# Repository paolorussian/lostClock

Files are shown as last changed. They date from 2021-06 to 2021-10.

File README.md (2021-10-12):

# "Swan" station flip-clock project files:
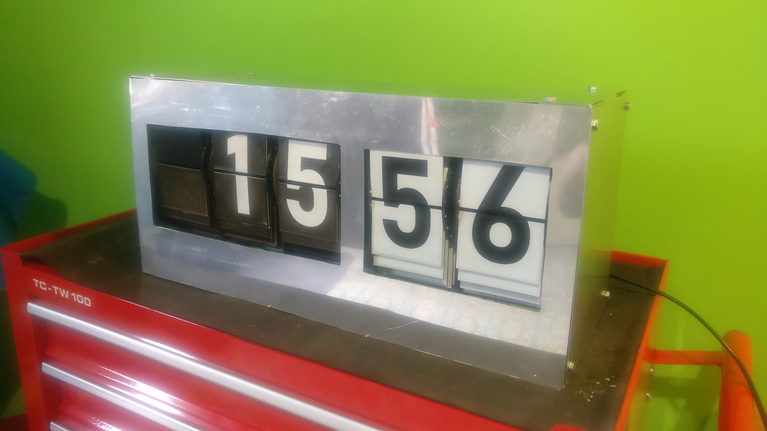
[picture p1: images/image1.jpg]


## THIS IS NOT A TUTORIAL

This LOST clock replica is a raspberry pi - based device which emulates the 108 minute countdown from the show, but can also function as a regular clock. Mode switch can be made by pushing an html button in a web server running from the same single python file.

Please note that, believe it or not, the clock in the show was added in computer graphics, meaning that some of its features cannot be 100% accurate in any replica: not only the case has no visible bolts or screws, but also the flaps should "magically change" from being only digits to only hieroglyphs. In the real world, we need bolts and also accommodate digits and hieroglyphs in the same flap drums, meaning that as the clocks runs through the digit flaps and then is supposed to start over (9,8,7,6,5,4,3,2,1,0.... 9 again) you will see the hieroglyphs briefly passing by, as the hieroglyph flap does exist and must be placed somewhere.

Also note that in this project the numbering is [0,1,2,3,4,5,6,7,8, BLANK, HIEROGLYPH, 9,8,7,6,5,4,3,2,1] totalling 20 flaps each drum. You may have noticed that the digits are duplicated: this is not an error, as in order to function also as a regular clock we should have also ascending numbers. This is because in split-flap displays like this drums can only turn in one direction meaning that if you want to obtain a countdown timer (like the one from the show) you should have descending numbers to minimize the amount of flaps skipped minute after minute. But if you want it to also function as a regular clock then without ascending numbers you would have to use the descending, but each time the drum advances one digit, to get to the next flap it would need to run through all the 19 following flaps every minute (or second). Having both descending and ascending numbering, we can use only the descending for the countdown mode, and only the ascending for the clock mode. 0 is shared intentionally and also the 9 because I'm lazy and I didn't modify my print to accommodate 21 flaps instead of 20.

### required materials and components
- a raspberry pi (Pi3B+, PI4, or Zero W)
- 5 * 28BYJ-48 stepper motors with 
- 5 * motor drivers UNL2003
- 5 * KY-010 photo interrupters
- 5 * ball bearings 5mm * 11mm * 4mm
- 5V 3A stabilized power adapter (to power the thing from regular 220v lines or plugs)
- lots of dupont cables or whatever you prefer to use for connections
- a couple of 3.5mm * 1mm * 1m flat aluminum profiles
- a couple of 6mm diameter * 1m cylinder hollow alumunum profiles 
- a couple of 4mm * 1m screw bar (metal rods that basically are endless screws, like in 3d printer shafts). this and the previous are needed to hold the frame together
- m4 nuts and bolts of various length
- m2 nuts and bolts for the photo interrupter tiny holes
- 1mm headless nails (you need to insert one of these nails in the drum little hole so that it passes through the photo interrupter each drum turn, auto-configuring the motor initial position, which in case you power off the device there is no way to know otherwise)
- black spray paint (not really necessary)

### what do you need to 3D print (stl included in the project's stl directory)
- 5 * drum L
- 5 * drum R
- 100 flaps (20 each drum)

## Assembly

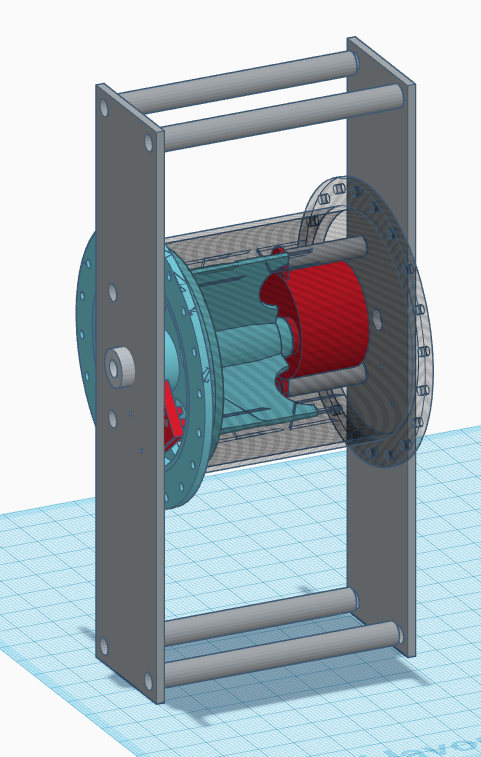
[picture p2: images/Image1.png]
fully assembled
 *an assembled single drum*

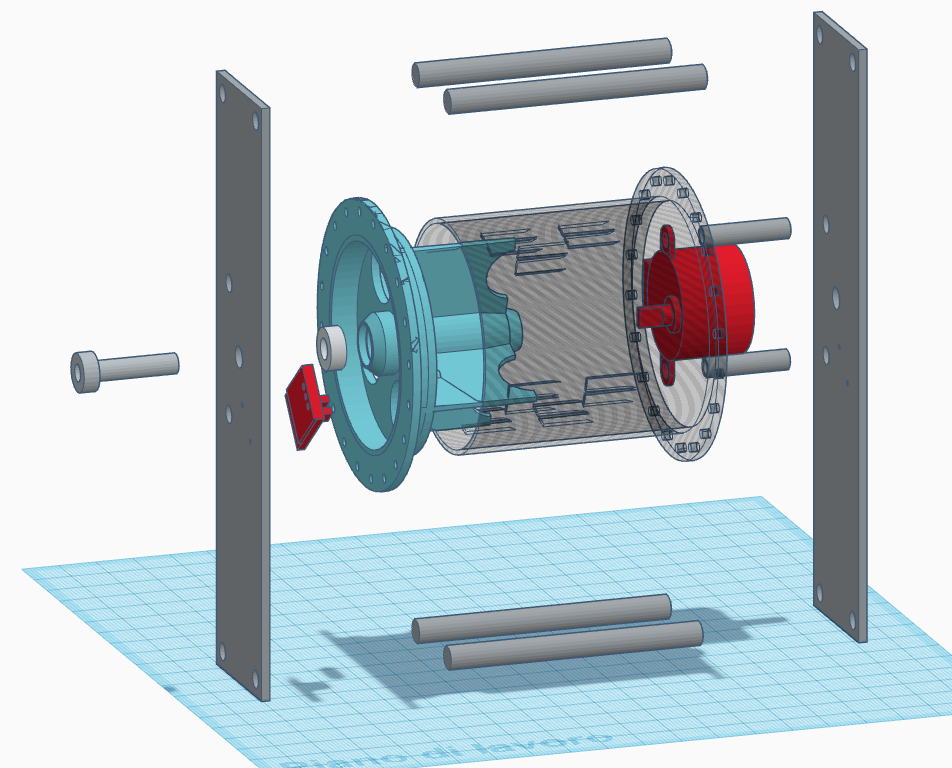
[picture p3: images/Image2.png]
disassembled
 *an exploded single drum*

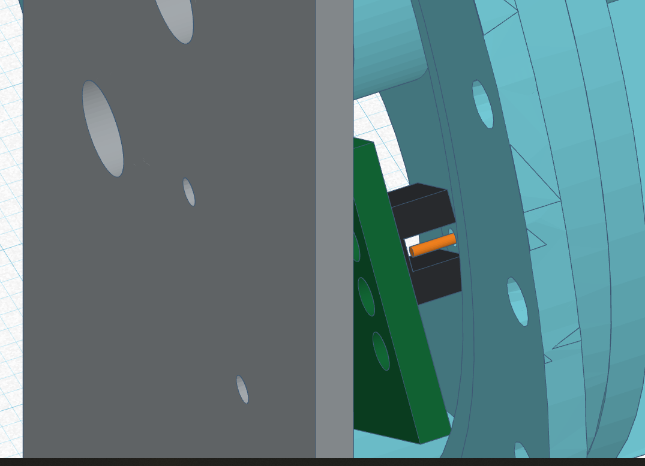
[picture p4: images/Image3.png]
nail and photo interrupter
 *nail and photo interrupter*

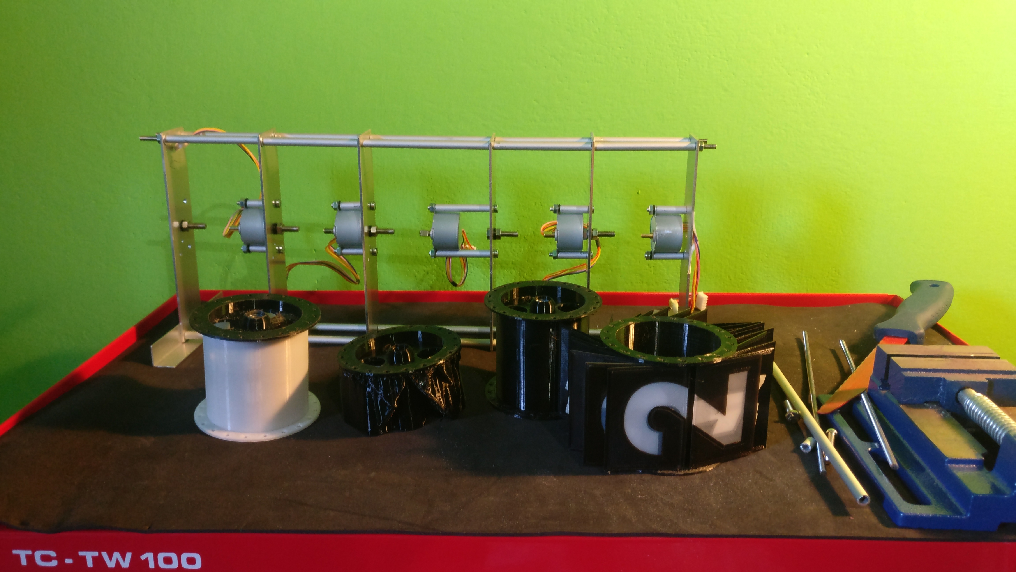
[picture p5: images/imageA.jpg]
frame assembled partial
 *unfinished frame assembled*

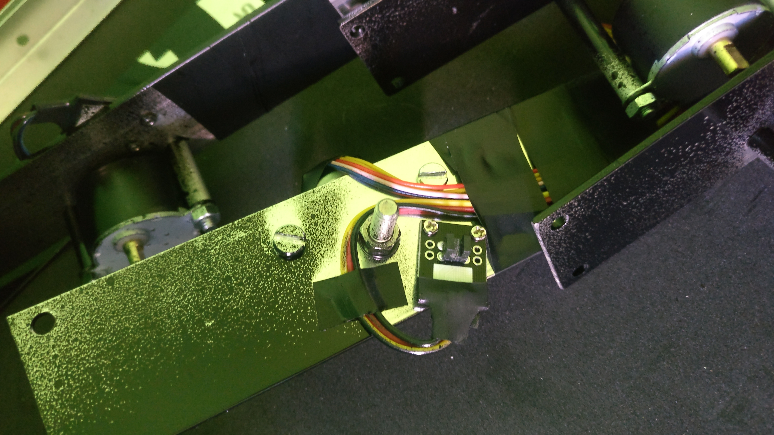
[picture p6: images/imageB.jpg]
photo interrupter
 *photo interrupter*

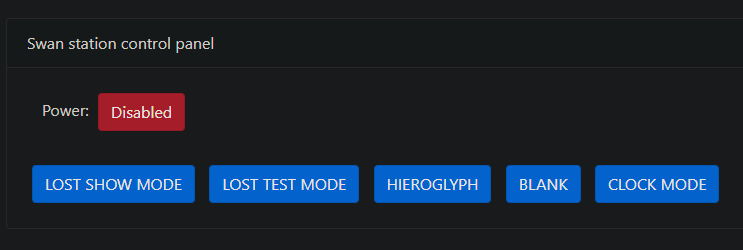
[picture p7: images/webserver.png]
webserver


*web interface to switch between modes*
- lost show mode: full 109 minute timer (108.59.99...), under 4 minutes "seconds" drums are enabled, with sounds (volume 100%)
- lost test mode: same as lost show mode but the timer starts at 2 minutes, with 50% volume
- hieroglyph: displays hieroglyphs on each drum (static)
- blank: display blank flaps on each drum (static)
- clock mode: works as a regular HH:MM clock. As the raspberry pi hasn't got any battery to store time, and there's no real time clock, time is got from the internet as soon as the raspberry pi manages to connect to the wifi. It usually takes a minute or two, depending on the signal strenght and (mostly) Murphy's laws.

credits:
https://www.thingiverse.com/thing:3493999 Martin1111 for the drum and flap design, which, however got modified to accommodate other components.

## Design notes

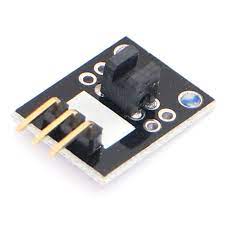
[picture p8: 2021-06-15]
images/ky010.jpg

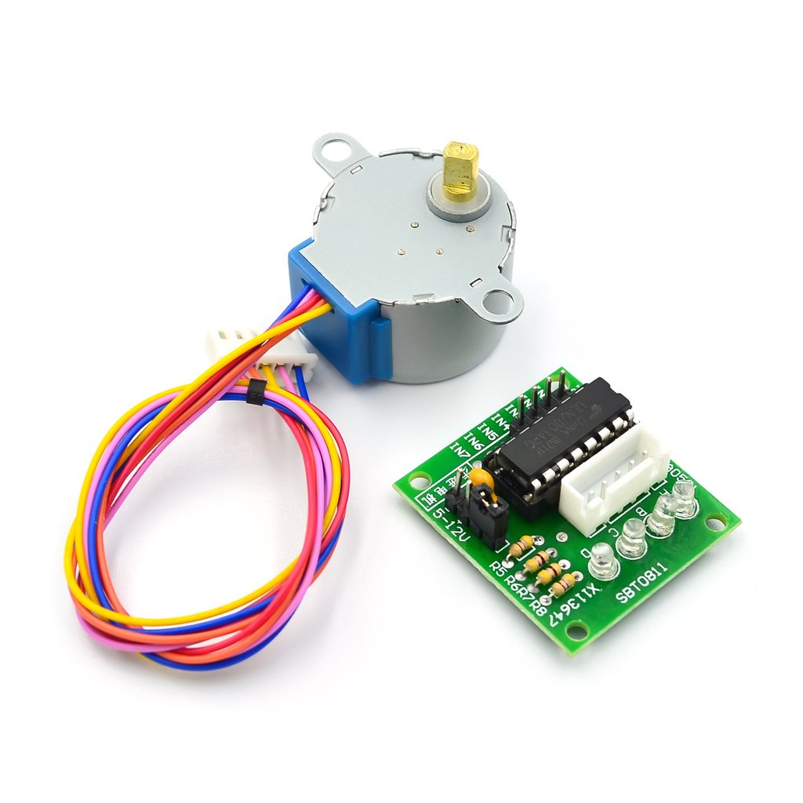
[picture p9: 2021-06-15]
images/motor.jpg

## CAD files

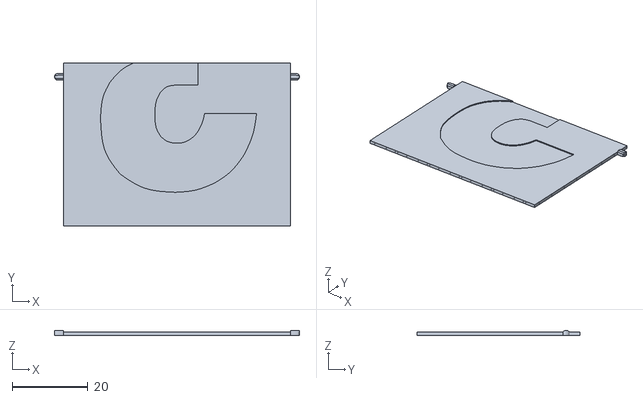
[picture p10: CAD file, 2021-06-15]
stl/C2.stl
64.9 x 43.1 x 1.20

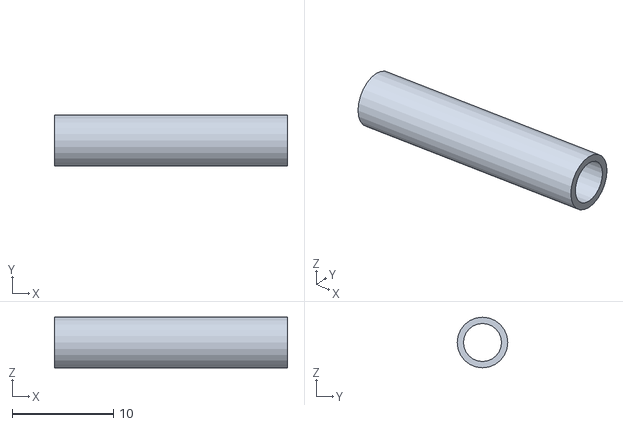
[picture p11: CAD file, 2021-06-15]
stl/supportB.stl
23.0 x 5.00 x 5.00

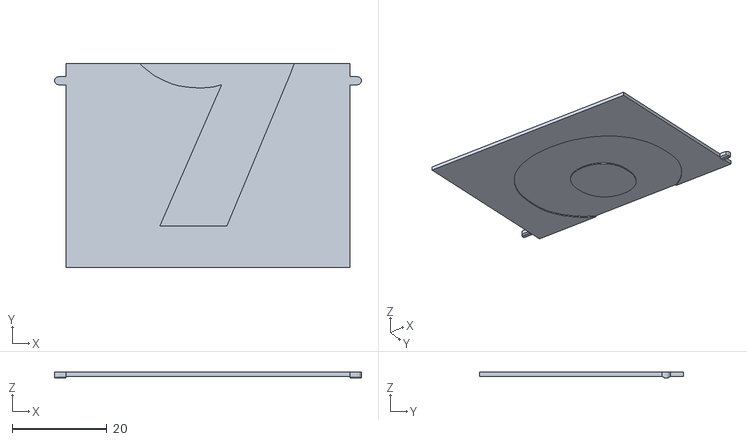
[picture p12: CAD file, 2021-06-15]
stl/F9.stl
64.8 x 43.1 x 1.20

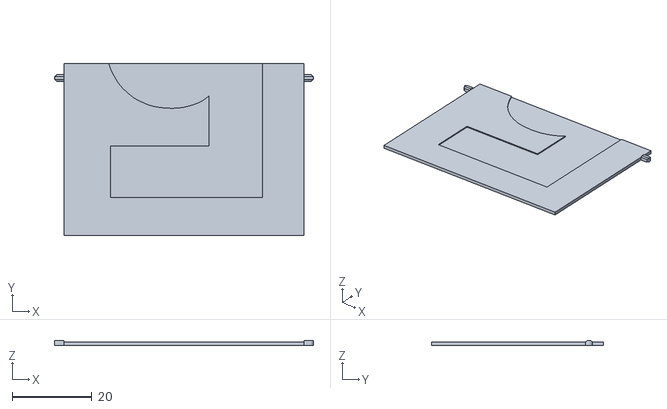
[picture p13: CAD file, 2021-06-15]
stl/C4.stl
64.9 x 43.1 x 1.20

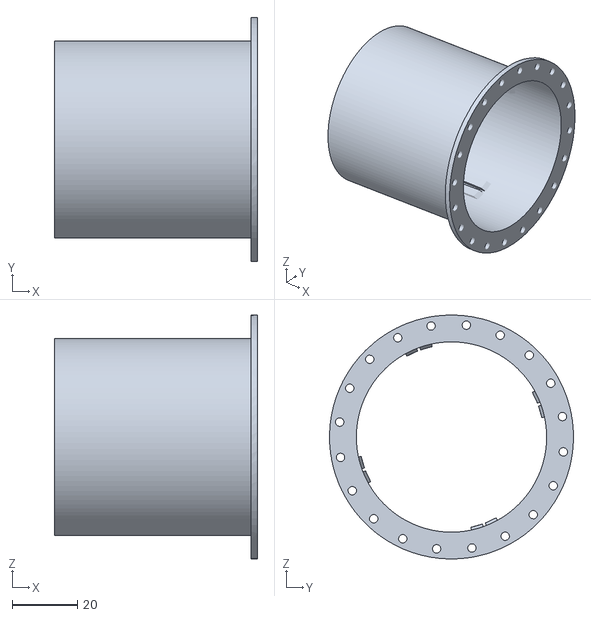
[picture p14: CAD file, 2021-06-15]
stl/drumR.stl
62.5 x 75.0 x 75.0

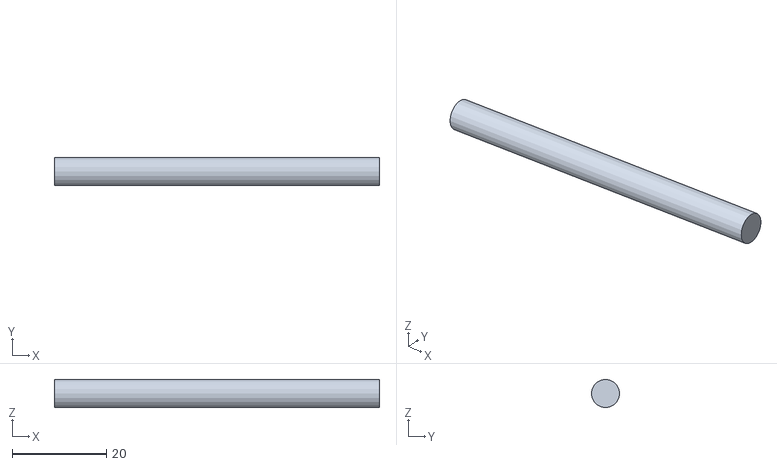
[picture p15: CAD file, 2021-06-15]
stl/supportA.stl
69.0 x 6.00 x 6.00

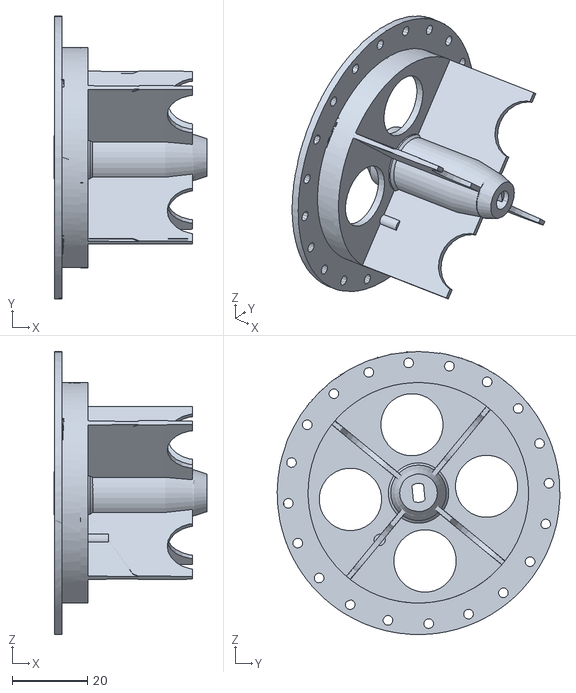
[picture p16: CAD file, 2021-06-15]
stl/DrumL.stl
40.6 x 75.0 x 75.1

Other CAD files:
stl/FLAP_EMPTY.stl
stl/X9 drum4.stl
stl/C5.stl
stl/BX drum0.stl
stl/C1.stl
stl/C6 v2.stl
stl/F9MOD.stl
stl/F5.stl
stl/BX drum2.stl
stl/F0.stl
stl/X9 drum2.stl
stl/BX drum1.stl
stl/BX drum3.stl
stl/BX drum4.stl
stl/C0.stl
stl/C3.stl
stl/C7.stl
stl/C8.stl
stl/F1.stl
stl/F1mod3.stl
stl/F2.stl
stl/F3.stl
stl/F4.stl
stl/F6.stl
stl/F7.stl
stl/F8.stl
stl/F8MOD.stl
stl/X9 EMPTY.stl
stl/X9 drum0.stl
stl/X9 drum1.stl
stl/X9 drum3.stl
stl/frameBar.stl

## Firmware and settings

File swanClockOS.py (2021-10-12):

import RPi.GPIO as GPIO
import time
import datetime
import sys
import traceback
import threading
import os
from flask import (Flask, render_template, request)

isPowerOn = True


app = Flask(__name__)
@app.route("/")
def home():
    return render_template("index.html",enabled=isPowerOn)

@app.route("/switch")
def changeMode():
    global mode
    global start_time
    global current_time
    global isCalibrated
    global timerLostMinutes
    global timerLostSeconds
    global volumeAttenuation

    m = request.args.get("mode", type = str)
    print("pre", mode, "will change in", m)

    if m=="LOST":
        print("setting LOST")
        start_time=time.time()
        current_time=start_time
        mode=m
        timerLostMinutes = 109
        timerLostSeconds = 00
        volumeAttenuation = "-100"
        isCalibrated=[False,False,False,False,False]
        os.system('omxplayer  --no-keys --vol -100 /home/pi/Documents/python/lostClock/GLaDOS-timermode.wav &')
    elif m=="CLOCK":
        print("setting CLOCK")
        start_time=time.time()
        current_time=start_time
        mode=m
        os.system('omxplayer  --no-keys --vol -100 /home/pi/Documents/python/lostClock/GLaDOS-clockmode.wav &')
        isCalibrated=[False,False,False,False,False]
    elif m=="LOST_TEST":
        print("setting LOST TEST")
        
        start_time=time.time()
        current_time=start_time
        timerLostMinutes = 2
        timerLostSeconds = 00
        volumeAttenuation = "-1000"
        mode="LOST"
        os.system('omxplayer  --no-keys --vol -100 /home/pi/Documents/python/lostClock/GLaDOS-timermode.wav &')
        isCalibrated=[False,False,False,False,False]
    elif m=="powerOn":
        print("power on!")
        isPowerOn = True
    elif m=="powerOff":
        print("power off!")
        isPowerOn = False
    elif m=="HIEROGLYPH":
        print("setting HIEROGLYPH")
        mode="HIEROGLYPH"
        isCalibrated=[False,False,False,False,False]
    elif m=="BLANK":
        print("setting BLANK")
        mode="BLANK"
        isCalibrated=[False,False,False,False,False]
    
    return render_template("index.html",enabled=isPowerOn)


hostName = "192.168.0.2"
serverPort = 8081
serverEnabled = False
soundsEnabled = True
volumeAttenuation = "-100"
######################################################


GPIO.setwarnings(False)

GPIO.setmode(GPIO.BCM)
#GPIO.setmode(GPIO.BOARD)

pinSensors = [27,22,5,24,8]

controlPins = [ [2,3,4,17],
                [10,9,11,0],
                [6,13,19,26],
                [14,15,18,23],
                [12,16,20,21] ]

isSensorHit = [False, False, False, False, False]
isCalibrated = [False, False, False, False, False]
isDrumActive = [False, False, False, False, False]

numberOfDrums = len(controlPins)

for drum in range(numberOfDrums):
    for pin in range(4):
        GPIO.setup(controlPins[drum][pin],GPIO.OUT)
        GPIO.output(controlPins[drum][pin],0)


for pin in range(len(pinSensors)):
    GPIO.setup(pinSensors[pin],GPIO.IN)

seq = [ [1,0,0,1],
        [1,1,0,0],
        [0,1,1,0],
        [0,0,1,1] ]

drumPositions = [0,0,0,0,0]
drumTargetPositions = [0,0,0,0,0]
drumOffsets = [0,0,0,0,0]

simpleCounter = 0
mode = "CLOCK"
#mode = "LOST"
timerLostMinutes = 109
#timerLostMinutes = 2
timerLostSeconds = 00
fullTurn = 2042;
stepsPerFlap = fullTurn / 20

flapsCrono = [0,1,2,3,4,5,6,7,8,11]
flapsTimer = [0,19,18,17,16,15,14,13,12,11]
flapsHieroglyphPosition = 1024
flapsEmptyPosition = 922

def readSensors():
    for drum in range(numberOfDrums):

        if GPIO.input(pinSensors[drum]):
            isSensorHit[drum] = True
        else:
            if isSensorHit[drum]:

#                drumPositions[drum] = 0 # self calibrate position
                drumPositions[drum] = drumOffsets[drum]

                if not isCalibrated[drum]:
                    isCalibrated[drum] = True
                isSensorHit[drum] = False



###########################################
def moveDrums():

    for step in range(4):
        for pin in range(4):
            for drum in range(numberOfDrums):
                if (isDrumActive[drum]):

                    if step == 0:
                        drumPositions[drum] += 1

                        if drumPositions[drum] >= fullTurn:
                            drumPositions[drum] -= fullTurn
                            drumTargetPositions[drum] -= fullTurn

                    GPIO.output(controlPins[drum][pin], seq[step][pin])
                else:
                    GPIO.output(controlPins[drum][pin], GPIO.LOW)

        time.sleep(0.002)

###########################################

def serverStart():
    app.run(host="0.0.0.0", port = "5000", threaded=True, use_reloader=False)

try:

    if __name__ == "__main__":
        app.config.host = "0.0.0.0"
        threading.Thread(target=serverStart).start()

    os.system('omxplayer  --no-keys --vol -100 /home/pi/Documents/python/lostClock/GLaDOS-clockonline.wav &')
    start_time = time.time()
    current_time = start_time

    while True:

        current_time = time.time()

        if mode == "CRONO":
            tick = int(current_time - start_time)
            simpleCounter = tick
            flapTargets = list(map(int, str(simpleCounter).zfill(5)))
            flapTargets.reverse()

        elif mode == "LOST":
            if time.time() - start_time >= 1:
               start_time = time.time()
               timerLostSeconds -= 1

               if timerLostSeconds < 1:
                   if timerLostMinutes > 0:
                       timerLostSeconds = 60
                       if timerLostMinutes >= 1:
                           timerLostMinutes -= 1
                   else:
                       timerLostSeconds = 0

               if soundsEnabled:
                   if (timerLostSeconds % 2) == 0 and (timerLostMinutes == 0 and timerLostSeconds > 10):
                       #os.system('mpg321 /home/pi/Documents/python/lostClock/beepB.mp3 &')
                       os.system('omxplayer  --no-keys --vol '+ volumeAttenuation + ' /home/pi/Documents/python/lostClock/beepB.mp3 &')
                   elif timerLostSeconds % 2 == 0 and (timerLostMinutes < 5 and timerLostMinutes > 0):
                       #os.system('mpg321 /home/pi/Documents/python/lostClock/beepA.mp3 &')
                       os.system('omxplayer  --no-keys --vol '+ volumeAttenuation + ' /home/pi/Documents/python/lostClock/beepA.mp3 &')
                   elif timerLostMinutes == 0 and timerLostSeconds <= 10 and timerLostSeconds >= 1:
                       #os.system('mpg321 /home/pi/Documents/python/lostClock/beepB.mp3 &')
                       os.system('omxplayer  --no-keys --vol '+ volumeAttenuation + ' /home/pi/Documents/python/lostClock/beepB.mp3 &')
                   

            valueMinutes = list(map(int,str(timerLostMinutes).zfill(3)))
            if timerLostMinutes > 4:
                valueSeconds = [0, 0]
            else:
                valueSeconds = list(map(int,str(timerLostSeconds).zfill(2)))

            flapTargets = [valueMinutes[0],valueMinutes[1],valueMinutes[2], valueSeconds[0],valueSeconds[1]]
            flapTargets.reverse()
            
            if timerLostMinutes == 0 and timerLostSeconds == 0:
                flapTargets = [-1,-1,-1,-1,-1]

        elif mode == "CLOCK":
            now = datetime.datetime.now()
            hourArr = list(map(int, str(now.hour).zfill(2)))
            minArr = list(map(int, str(now.minute).zfill(2)))
            flapTargets = [-1, hourArr[0], hourArr[1], minArr[0], minArr[1]]
            flapTargets.reverse()

        elif mode == "HIEROGLYPH":
            flapTargets = [flapsHieroglyphPosition, flapsHieroglyphPosition, flapsHieroglyphPosition, flapsHieroglyphPosition, flapsHieroglyphPosition]
        elif mode == "BLANK":
            flapTargets = [flapsEmptyPosition, flapsEmptyPosition, flapsEmptyPosition, flapsEmptyPosition, flapsEmptyPosition]


        for drum in range(numberOfDrums):

            if not isCalibrated[drum]:    #if not calibrated yet, move drum until it is
                isDrumActive[drum] = True

            else:                         # if this drum is already calibrated, behave normally

                if flapTargets[drum] != -1:
                    if mode == "CLOCK":
                        newPos = flapsCrono[flapTargets[drum]] * stepsPerFlap
                    elif mode == "LOST":
                        newPos = flapsTimer[flapTargets[drum]] * stepsPerFlap
                    else:
                        newPos = flapTargets[drum]
                else:
                    if mode == "CLOCK":
                        newPos = flapsEmptyPosition
                    elif mode == "LOST":
                        newPos = flapsHieroglyphPosition

                if newPos < drumTargetPositions[drum]:
                    newPos += fullTurn

                drumTargetPositions[drum] = newPos # + drumOffsets[drum]

                if drumTargetPositions[drum] > drumPositions[drum] + drumOffsets[drum]:
                    isDrumActive[drum] = True

                else:
                    isDrumActive[drum] = False

        readSensors()
        moveDrums()

except KeyboardInterrupt:
    print("Interrupted by keyboard")

except Exception as err:
    print("EXCEPTION!")
    print("Ops!", err)
    
    

finally:
    #GPIO.cleanup()
    for drum in range(numberOfDrums):
        for pin in range(4):
            GPIO.output(controlPins[drum][pin], GPIO.LOW)
            exit(0)



exit(0)

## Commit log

2021-05-31 drum 5 sensor changed from gpio25 to gpio8
2021-06-16 webpage power on-off
